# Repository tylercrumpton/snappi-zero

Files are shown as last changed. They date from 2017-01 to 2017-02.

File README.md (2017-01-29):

# SNAPpi Zero
Raspberry Pi Zero HAT with a Synapse SNAP module.

pcb-top pcb-bottom

## Overview
The **SNAPpi Zero** is a HAT ("Hardware Attached on Top") for the Raspberry Pi Zero board.
It adds a Synapse RF- or SM-series 802.15.4 wireless module that can be programmed using the
SNAPpy language, based on Python.

## Operation
The **SNAPpi Zero**'s SNAP module is connected via UART1 to the Raspberry Pi's UART GPIO pins.
Additionally, the SNAP module's reset pin is connected to a Raspberry Pi, and three SNAP GPIO
are hooked up to LEDs on the **SNAPpi Zero** board. The pin mappings are as follows:

| Description | RF Module Pin | SM Module Pin | Raspberry Pi GPIO |
|---|---|---|---|
| SNAP RX1 | 9 | G4 | BCM 14 |
| SNAP TX1 | 10 | H4 | BCM 15 |
| SNAP Reset  | 23 | H5 | BCM 17 |
| LED A | 4 | D1 | N/A |
| LED B | 3 | D2 | N/A |
| LED C | 2 | D3 | N/A |

[pcb-top]: https://cloud.githubusercontent.com/assets/1317406/22275825/f1805148-e274-11e6-8883-3e8dbbb4946e.png
[pcb-bottom]: https://cloud.githubusercontent.com/assets/1317406/22275830/f65ffa56-e274-11e6-8890-72a585ec53ba.png

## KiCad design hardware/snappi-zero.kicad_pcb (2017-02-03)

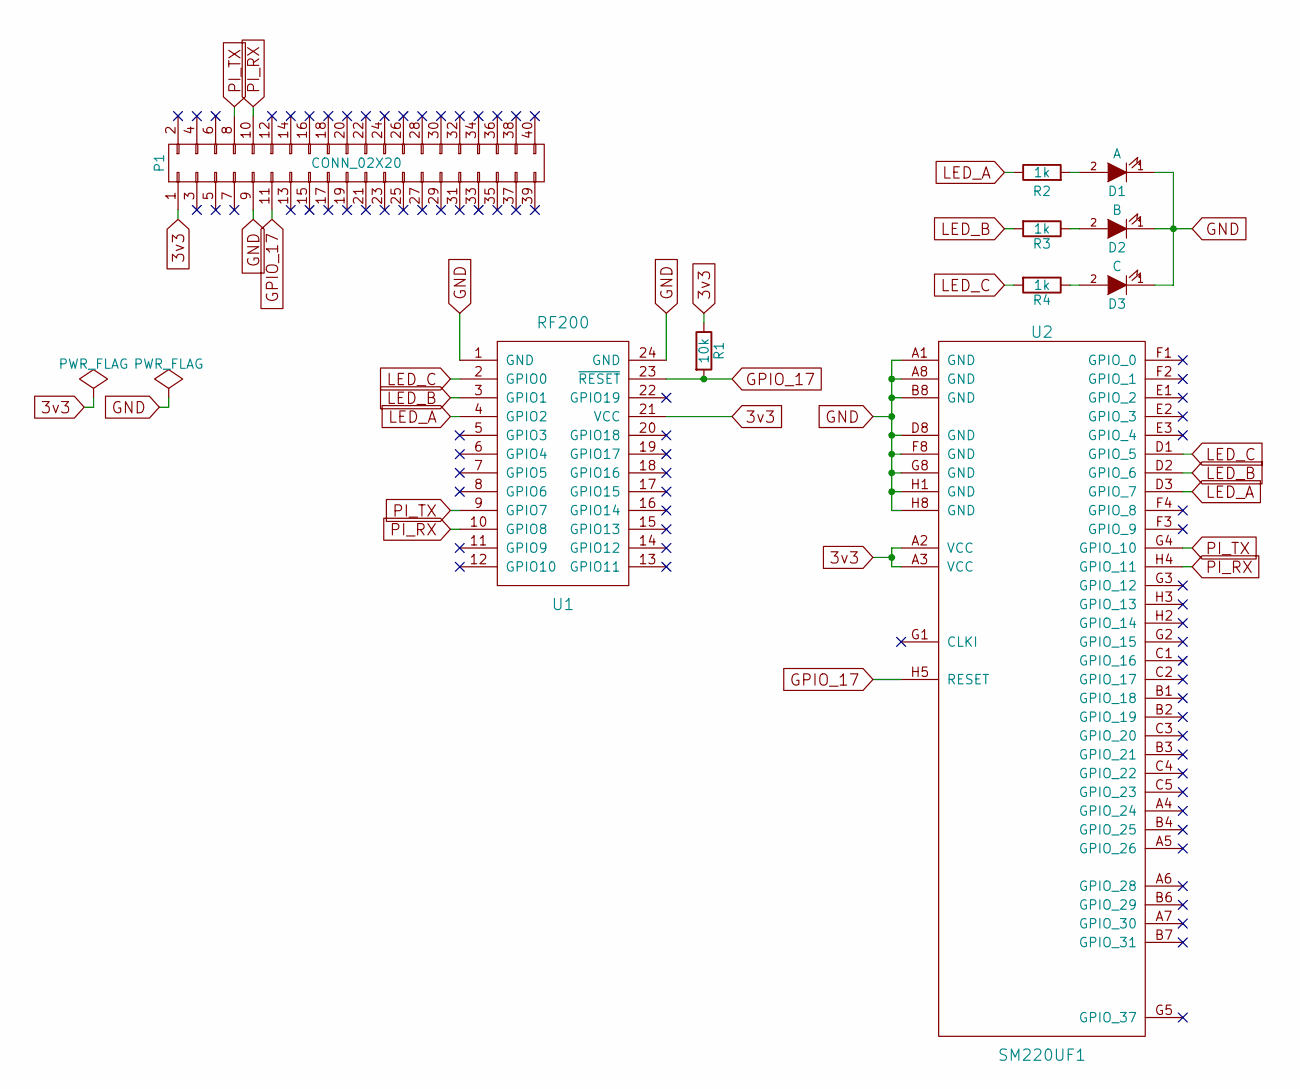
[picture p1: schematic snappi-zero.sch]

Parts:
D1: A; LED_1206
D2: B; LED_1206
D3: C; LED_1206
P1: CONN_02X20; Raspberry_Pi_Zero
R1: 10k; R_0805_HandSoldering
R2, R3, R4: 1k; R_0805_HandSoldering
U1: RF200; RF200_nosilk
U2: SM220UF1; SM200_nosilk

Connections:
3v3: P1.1, R1.1, U1.21 (VCC), U2.A2 (VCC), U2.A3 (VCC)
GND: D1.1 (K), D2.1 (K), D3.1 (K), P1.9, U1.1 (GND), U1.24 (GND), U2.A1 (GND), U2.A8 (GND), U2.B8 (GND), U2.D8 (GND), U2.F8 (GND), U2.G8 (GND), U2.H1 (GND), U2.H8 (GND)
GPIO_17: P1.11, R1.2, U1.23 (~RESET), U2.H5 (RESET)
LED_A: R2.1, U1.4 (GPIO2), U2.D3 (GPIO_7)
LED_B: R3.2, U1.3 (GPIO1), U2.D2 (GPIO_6)
LED_C: R4.2, U1.2 (GPIO0), U2.D1 (GPIO_5)
unnamed: D1.2 (A), R2.2
unnamed: D2.2 (A), R3.1
unnamed: D3.2 (A), R4.1
PI_RX: P1.10, U1.10 (GPIO8), U2.H4 (GPIO_11)
PI_TX: P1.8, U1.9 (GPIO7), U2.G4 (GPIO_10)

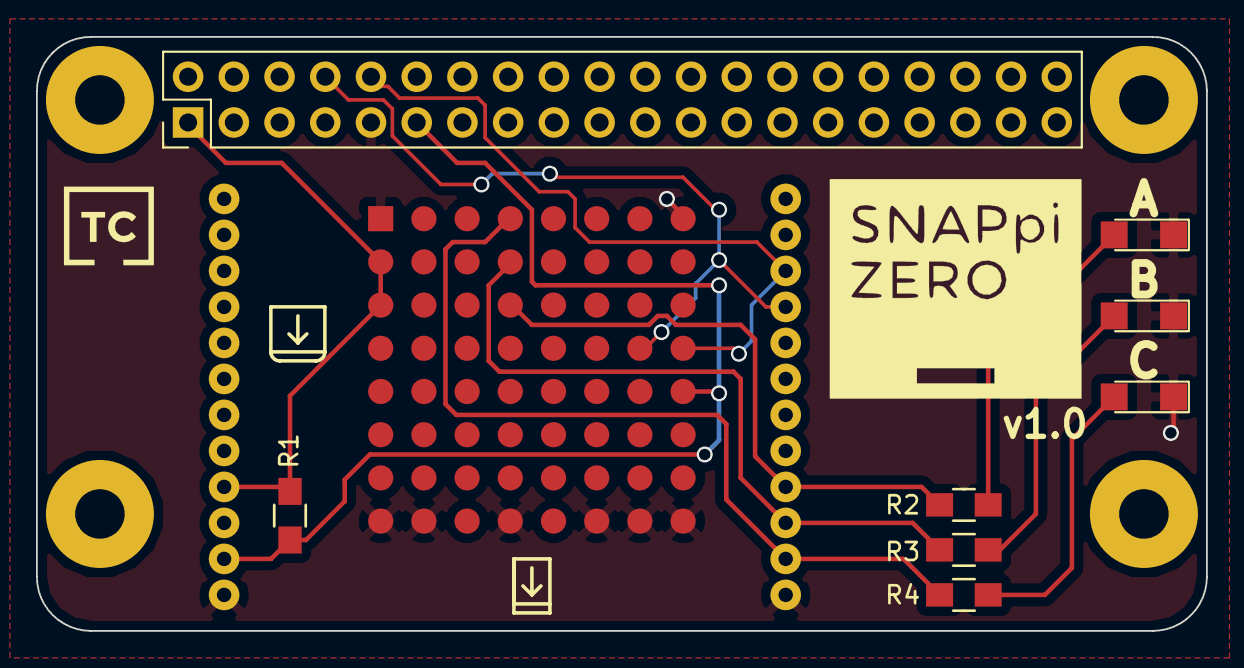
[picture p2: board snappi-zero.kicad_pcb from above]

Board: 2 copper layers, 65.0 x 33.0 mm, 11 parts (0 on the bottom side), 11 nets.

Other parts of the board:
svg2mod: G***; tc_30mm

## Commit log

2017-01-20 Create initial project setup.
    [snappi-zero.kicad_pcb, snappi-zero.sch]
2017-01-21 Design schematic.
    [snappi-zero.sch]
2017-01-22 Add LEDs and footprint assignment.
    [snappi-zero.sch]
2017-01-22 Fix Pi Zero connector pin count.
    [snappi-zero.sch]
2017-01-23 Place and route initial board.
    [snappi-zero.kicad_pcb, snappi-zero.sch]
2017-01-23 Add TC logo and finalize PCB.
    [snappi-zero.kicad_pcb]
2017-01-29 Fix missing TX/RX pins on SM modules.
    [snappi-zero.kicad_pcb, snappi-zero.sch]
2017-01-29 Fix Pi RX/TX pins.
    [snappi-zero.kicad_pcb, snappi-zero.sch]
2017-01-29 Add pin information to README.
2017-01-29 Add board images to README.
2017-02-03 Improve PCB copper pour shape.
    [snappi-zero.kicad_pcb]

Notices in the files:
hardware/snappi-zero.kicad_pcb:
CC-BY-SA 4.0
